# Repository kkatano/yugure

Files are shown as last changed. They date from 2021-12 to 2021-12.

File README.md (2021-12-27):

# Yugure

This project is currently primarily for experimental purposes. You are free to use the files in this project according to the license, but I do not recommend that use them as-is

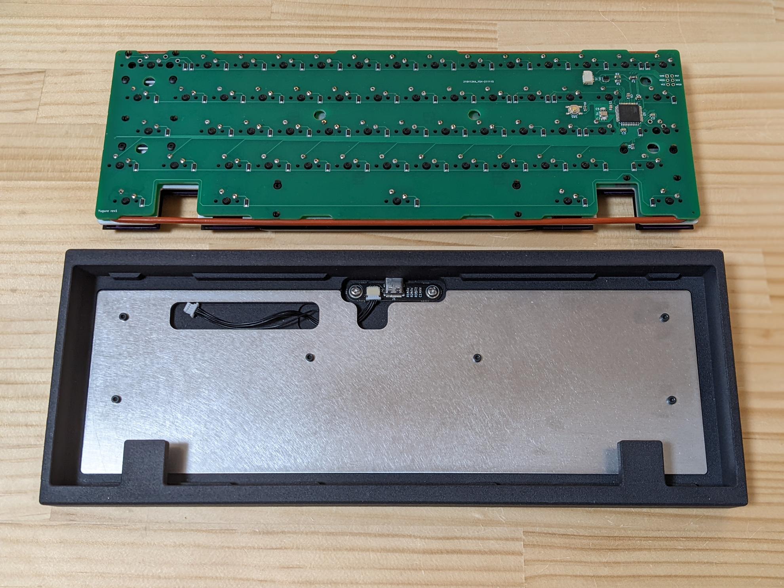
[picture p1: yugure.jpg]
Yugure


## Feature
- 60% WKL
- O-ring mount (friction fit)
- Single piece tray case
- Designed for SLS 3D printing

## Context
- I've never made a WKL board before and wanted to try it out
- Experimenting with some concepts
 - Unique gasket post location and shape. Testing how they affect the typing feel
 - Design of weight in tray case. Exploring the size and location of weight that are effective in reducing unwanted hollow sound, rather than making the case heavier

## Parts Guide
- Case
  - Use the the files contained in `case` directory
  - `case.step` is the design of the case. Order it from a service that supports SLS 3D printing
  - `weight.dxf` is the design of the weight to be attached to the case. Order 1.5mm thick from laser cutting service
  - Use 6 * 5mm M2 screws to secure the board
- PCB
  - Use the the files contained in `production` directory
  - The files is designed for ordering on JLCPCB. If you are ordering from any other manufacturer, please modify it as necessary
- Plate
  - Use the dxf files contained in `plate` directory
  - Order 1.5mm thick from laser cutting service
- Daughterboard
  - Use the [b-ken-ko's daughterboard](https://github.com/xyzz/b-ken-ko)
  - Use 2 * 3mm M3 screws to secure the board
- O-ring
  - Material: Silicone
  - Durometer(Hardness): 50A
  - AS568 number: 262
  - CS(Thickness): 3.53mm
  - ID(Inner Diameter): 177.39mm
  - OD(Outer Diameter): 184.45mm

## Notes
- This project is experimental and is not designed for serious use like production run
- You may be able to adjust the typing feel by changing the position and size of the mounting post
- There is a mounting post under the blocker, which may be difficult to make with CNC machining
- The PCB design includes the [MX_Alps_Hybrid](https://github.com/ai03-2725/MX_Alps_Hybrid/tree/b2517004a92a2ea354670c713a1530817f9da6df) designed by ai03 as a submodule. It is distributed under the MIT license

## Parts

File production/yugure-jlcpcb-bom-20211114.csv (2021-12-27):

Designator | Comment | Footprint | LCSC Part #
C1 C2 C3 | 0.1u | Capacitor_SMD:C_0805_2012Metric | C49678
C4 | 10u | Capacitor_SMD:C_0805_2012Metric | C15850
C5 C7 | 22p | Capacitor_SMD:C_0805_2012Metric | C1804
C6 | 1u | Capacitor_SMD:C_0805_2012Metric | C28323
D60 D59 D58 D57 D56 D55 D54 D53 D52 D51 D50 D49 D48 D47 D46 D45 D44 D43 D42 D41 D40 D39 D38 D37 D36 D35 D34 D33 D32 D31 D30 D29 D28 D27 D26 D25 D24 D23 D22 D21 D20 D19 D18 D17 D16 D15 D14 D13 D12 D11 D10 D9 D8 D7 D6 D5 D4 D3 D2 D1 | 1N4148 | Diode_SMD:D_SOD-123 | C81598
F1 | 500mA | Fuse:Fuse_1206_3216Metric | C70076
J1 | JST SH 4-pin | Connector_JST:JST_SH_SM04B-SRSS-TB_1x04-1MP_P1.00mm_Horizontal | C160404
R1 R2 | 22 | Resistor_SMD:R_0805_2012Metric | C17561
R4 R3 | 10k | Resistor_SMD:R_0805_2012Metric | C17414
SW1 | Reset | Button_Switch_SMD:SW_SPST_TL3342 | C318884
U1 | SRV05-4 | Package_TO_SOT_SMD:SOT-23-6 | C85364
U2 | ATmega32U4-AU | Package_QFP:TQFP-44_10x10mm_P0.8mm | C44854
Y1 | 16MHz | Crystal:Crystal_SMD_3225-4Pin_3.2x2.5mm | C13738

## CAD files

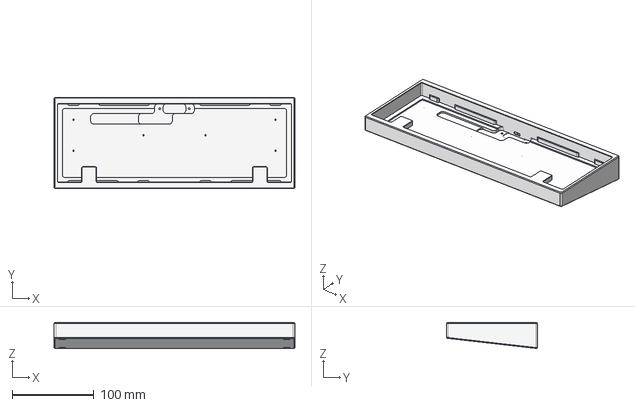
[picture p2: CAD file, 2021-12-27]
case/case.step
295.7 x 112.2 x 32.0 mm

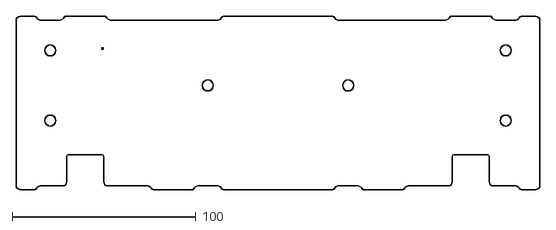
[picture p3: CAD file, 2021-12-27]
pcb/pcb-outline.dxf
284.7 x 94.2

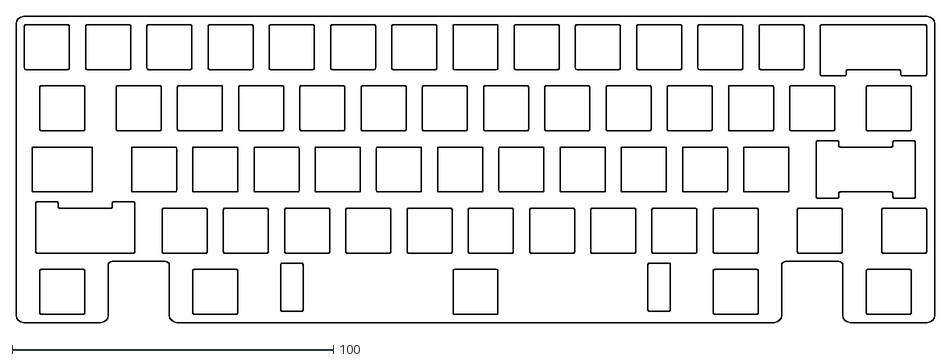
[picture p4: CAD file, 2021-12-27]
plate/plate.dxf
285.8 x 95.2

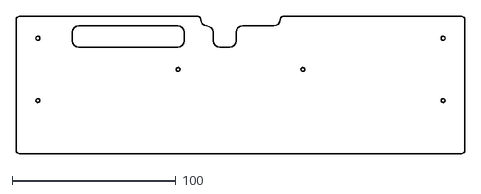
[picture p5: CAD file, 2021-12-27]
case/weight.dxf
274.3 x 83.8

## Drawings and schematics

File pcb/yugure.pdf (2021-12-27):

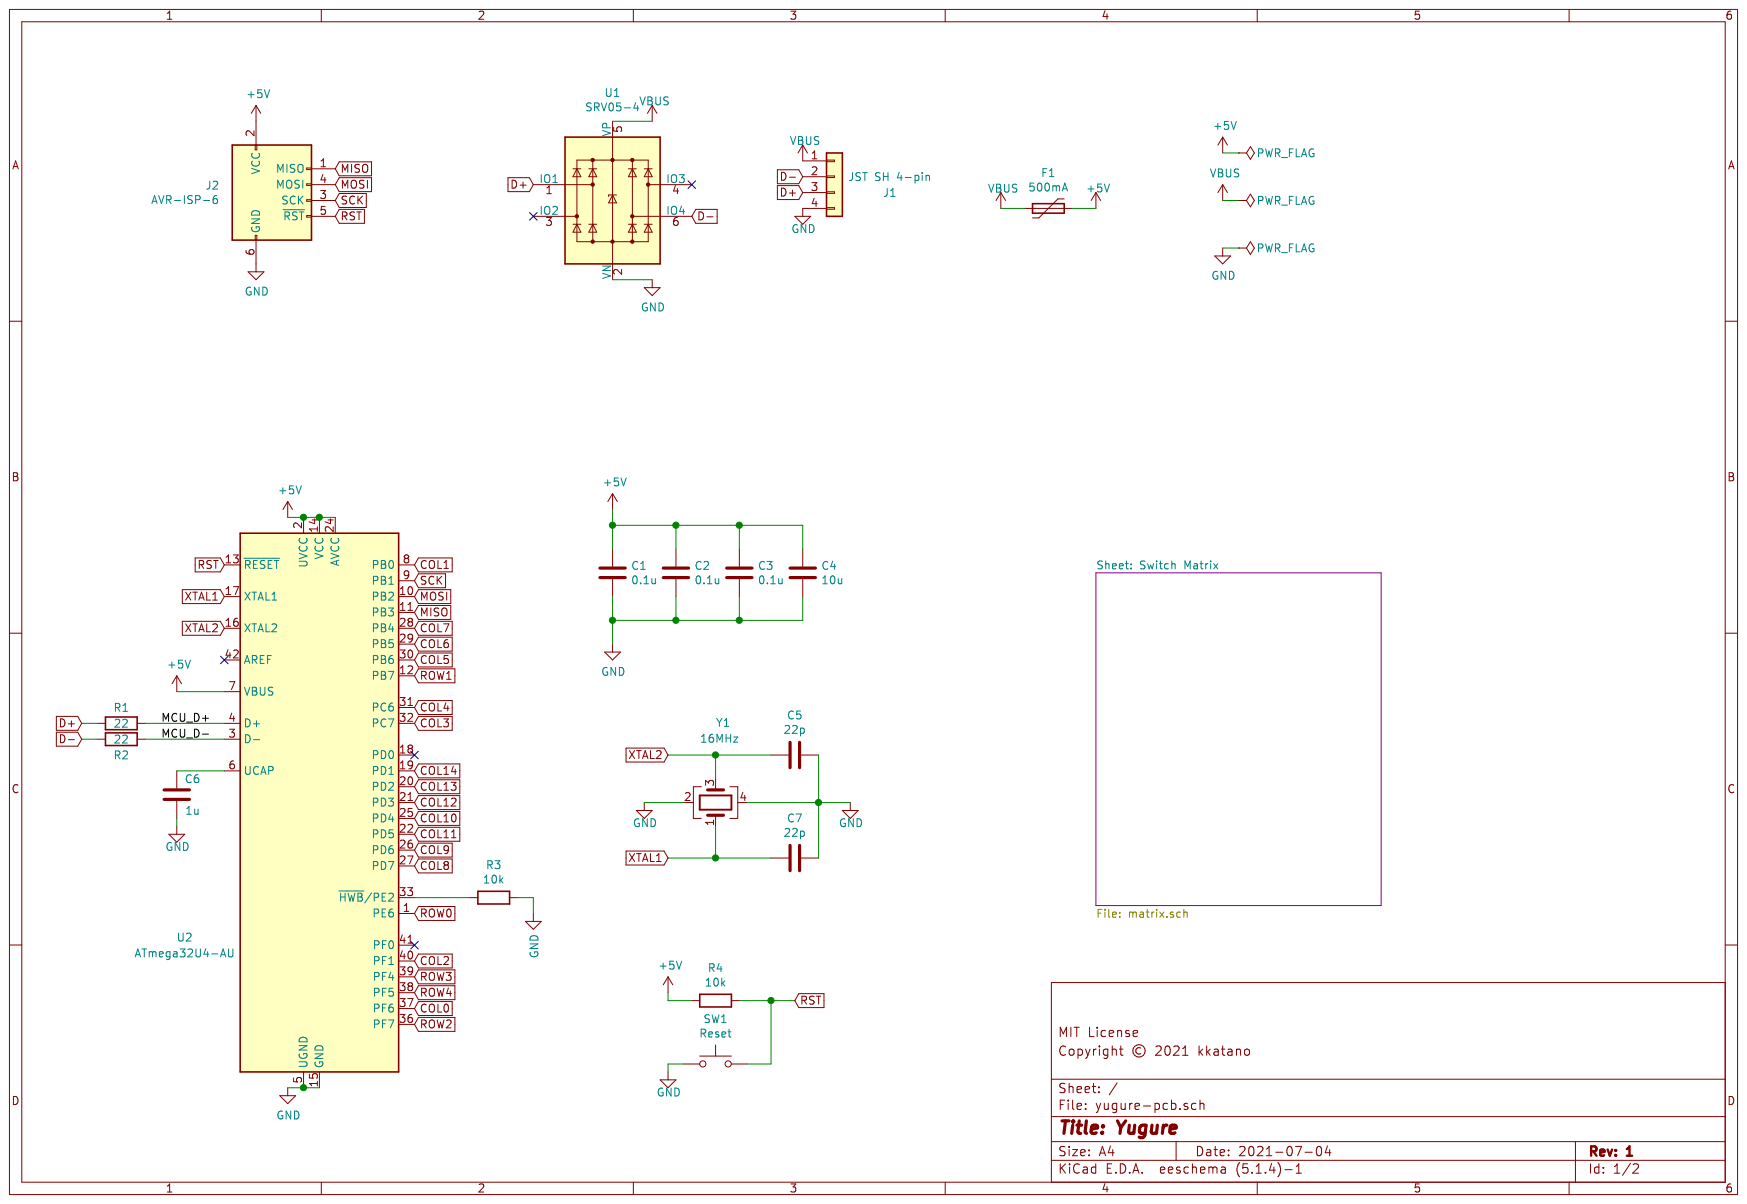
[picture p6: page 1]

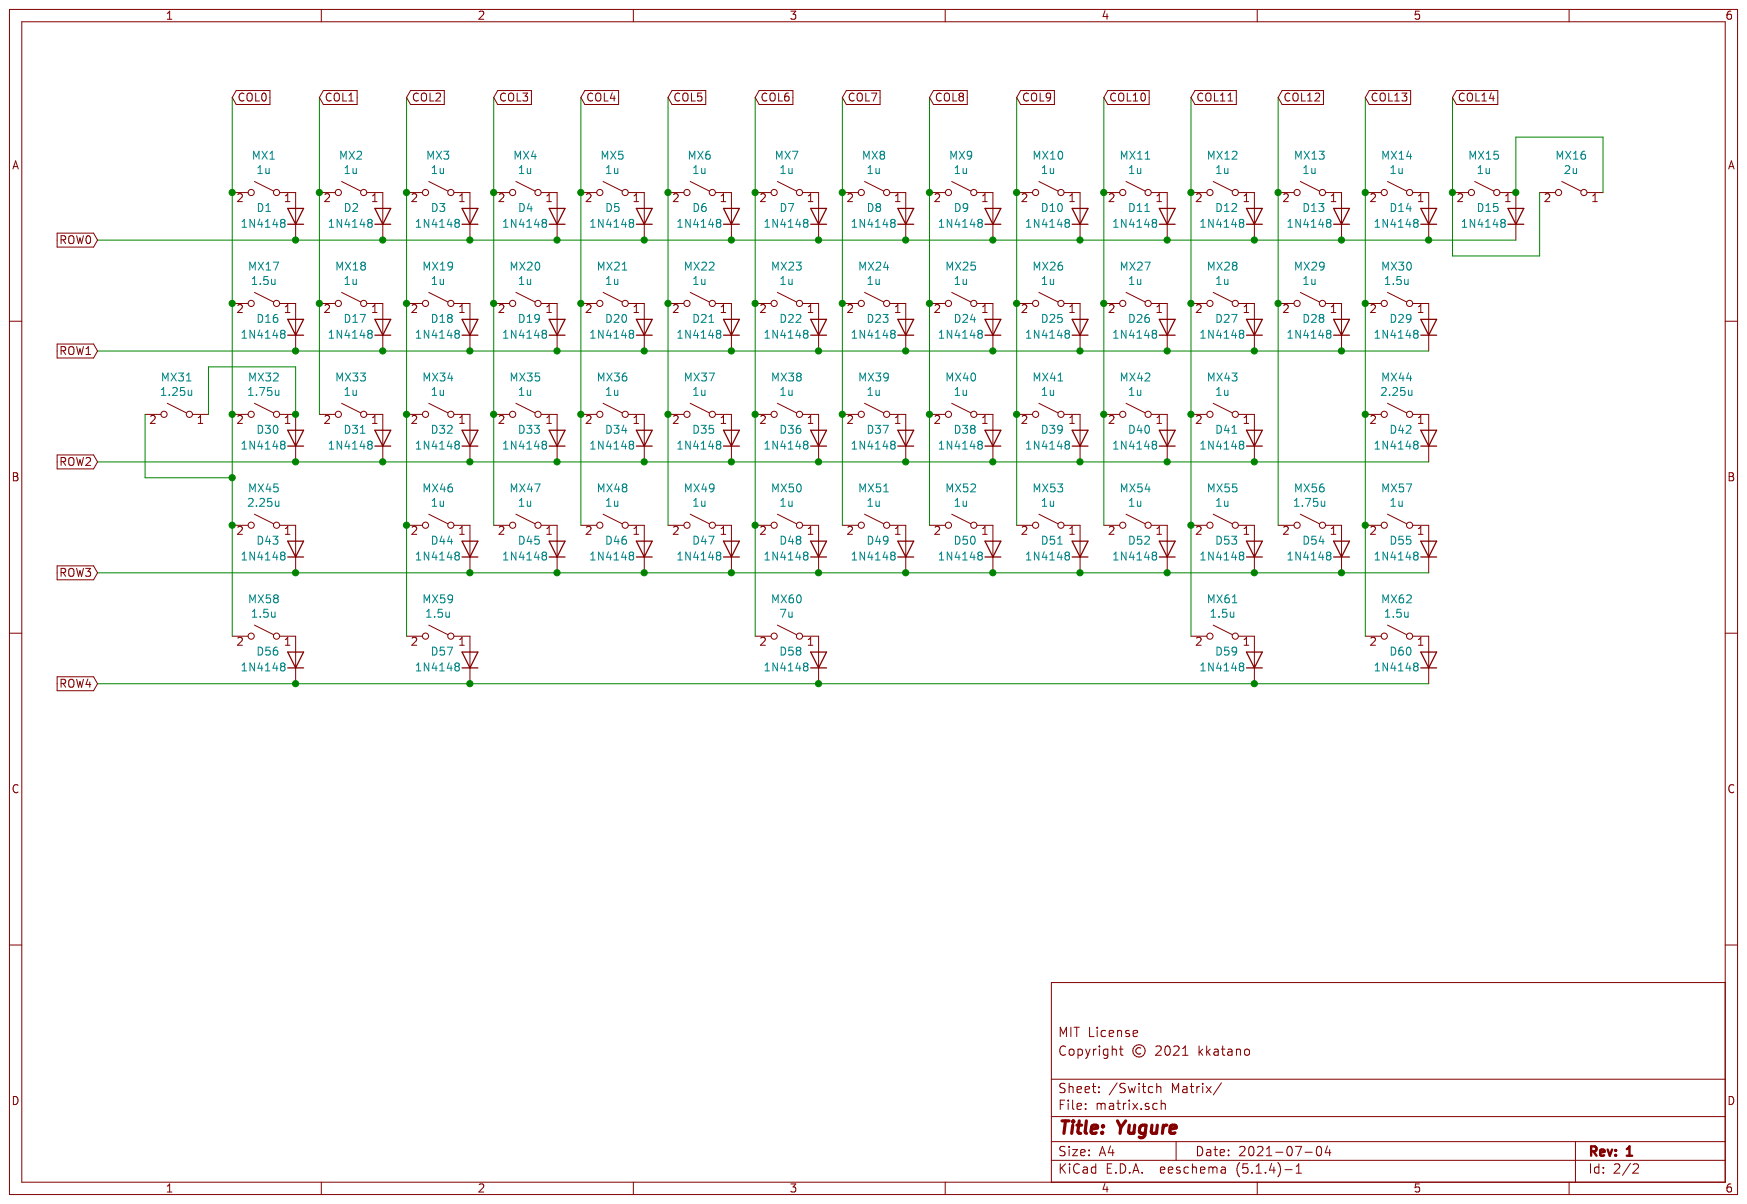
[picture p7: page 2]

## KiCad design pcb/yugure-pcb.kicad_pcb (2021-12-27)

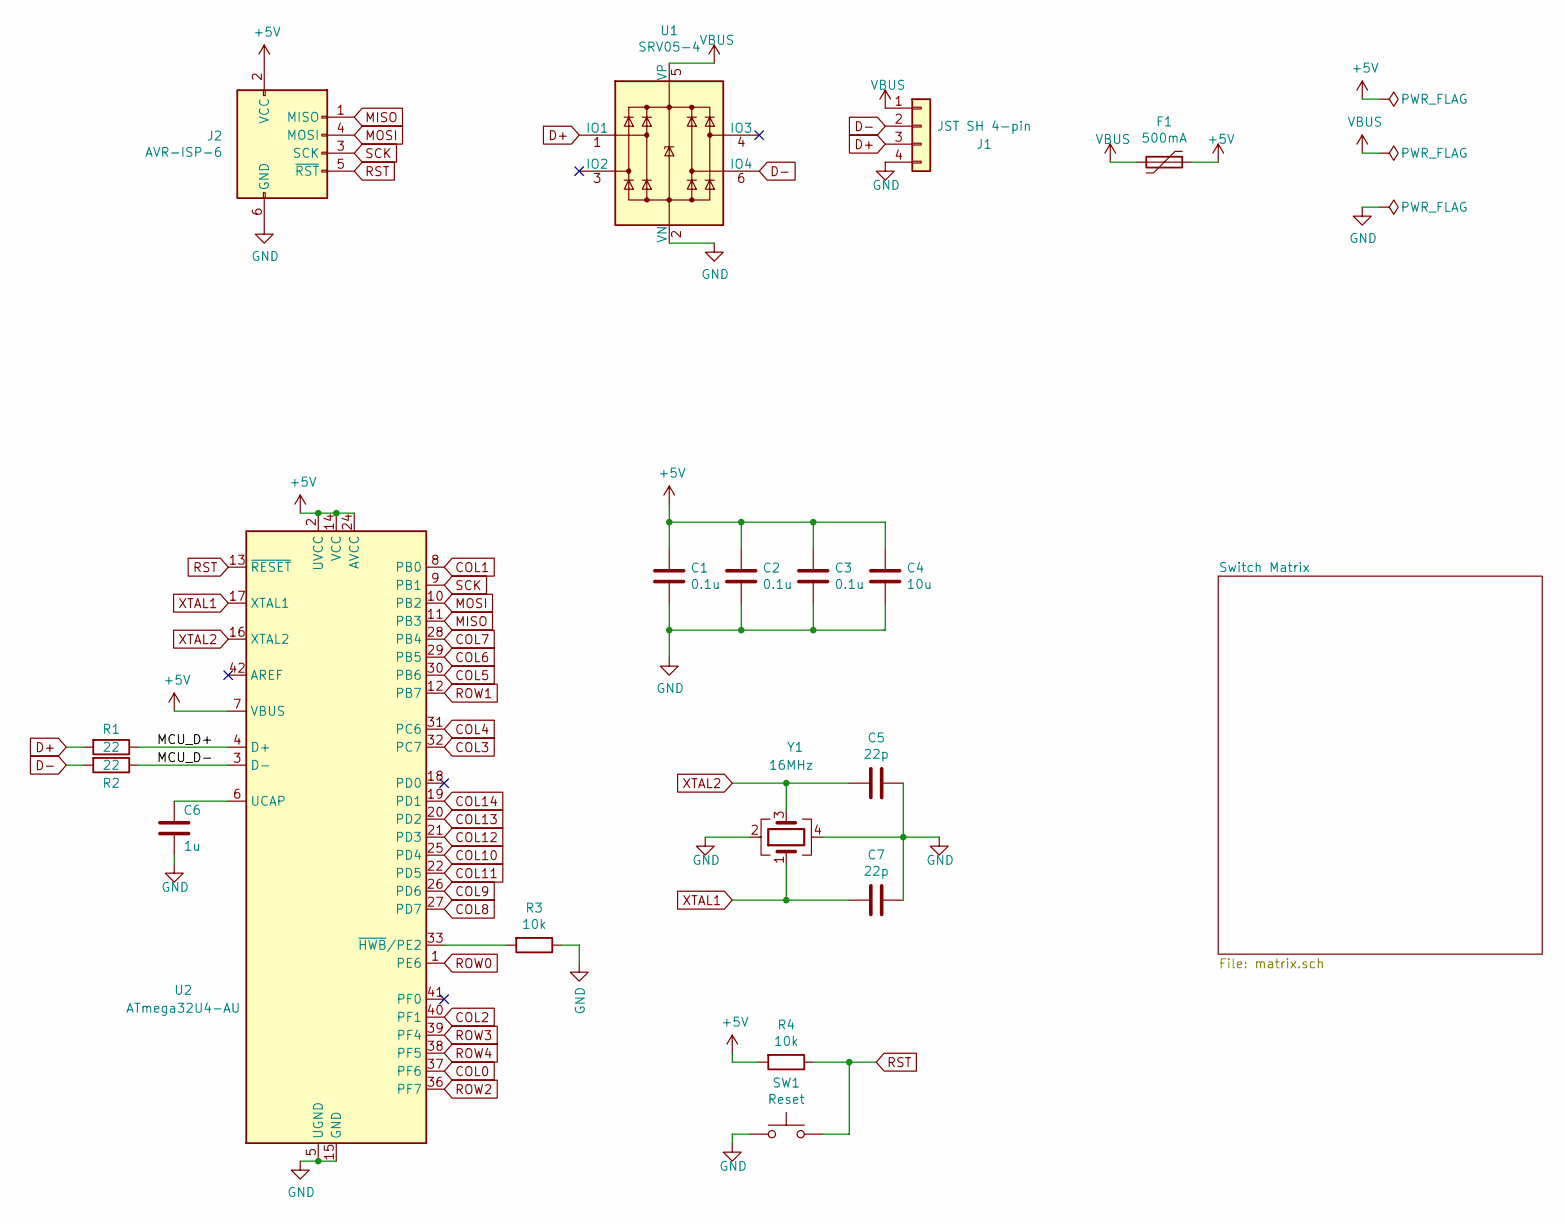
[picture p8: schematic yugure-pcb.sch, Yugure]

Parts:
C1, C2, C3: 0.1u; C_0805_2012Metric; LCSC Part # C49678
C4: 10u; C_0805_2012Metric; LCSC Part # C15850
C5, C7: 22p; C_0805_2012Metric; LCSC Part # C1804
C6: 1u; C_0805_2012Metric; LCSC Part # C28323
F1: 500mA; Fuse_1206_3216Metric; LCSC Part # C70076
J1: JST SH 4-pin; JST_SH_SM04B-SRSS-TB_1x04-1MP_P1.00mm_Horizontal; LCSC Part # C160404
J2: AVR-ISP-6; ISP
R1, R2: 22; R_0805_2012Metric; LCSC Part # C17561
R3, R4: 10k; R_0805_2012Metric; LCSC Part # C17414
SW1: Reset; SW_SPST_TL3342; LCSC Part # C318884
U1: SRV05-4; SOT-23-6; LCSC Part # C85364
U2: ATmega32U4-AU; TQFP-44_10x10mm_P0.8mm; LCSC Part # C44854
Y1: 16MHz; Crystal_SMD_3225-4Pin_3.2x2.5mm; LCSC Part # C13738

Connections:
+5V: C1.1, C2.1, C3.1, C4.1, F1.1, J2.2 (VCC), R4.2, U2.2 (UVCC), U2.7 (VBUS), U2.14 (VCC), U2.24 (AVCC), U2.34 (VCC), U2.44 (AVCC)
/MCU_D+: R1.1, U2.4 (D+)
/MCU_D-: R2.1, U2.3 (D-)
COL0: U2.37 (PF6); also elsewhere on the board
COL1: U2.8 (PB0); also elsewhere on the board
COL2: U2.40 (PF1); also elsewhere on the board
COL3: U2.32 (PC7); also elsewhere on the board
COL4: U2.31 (PC6); also elsewhere on the board
COL5: U2.30 (PB6); also elsewhere on the board
COL6: U2.29 (PB5); also elsewhere on the board
COL7: U2.28 (PB4); also elsewhere on the board
COL8: U2.27 (PD7); also elsewhere on the board
COL9: U2.26 (PD6); also elsewhere on the board
COL10: U2.25 (PD4); also elsewhere on the board
COL11: U2.22 (PD5); also elsewhere on the board
COL12: U2.21 (PD3); also elsewhere on the board
COL13: U2.20 (PD2); also elsewhere on the board
COL14: U2.19 (PD1); also elsewhere on the board
D+: J1.3, R1.2, U1.1 (IO1)
D-: J1.2, R2.2, U1.6 (IO4)
GND: C1.2, C2.2, C3.2, C4.2, C5.1, C6.2, C7.1, J1.4, J2.6 (GND), R3.1, SW1.1, U1.2 (VN), U2.5 (UGND), U2.15 (GND), U2.23 (GND), U2.35 (GND), U2.43 (GND), Y1.2, Y1.4
MISO: J2.1 (MISO), U2.11 (PB3)
MOSI: J2.4 (MOSI), U2.10 (PB2)
unnamed: C6.1, U2.6 (UCAP)
unnamed: R3.2, U2.33 (~HWB~/PE2)
ROW0: U2.1 (PE6); also elsewhere on the board
ROW1: U2.12 (PB7); also elsewhere on the board
ROW2: U2.36 (PF7); also elsewhere on the board
ROW3: U2.39 (PF4); also elsewhere on the board
ROW4: U2.38 (PF5); also elsewhere on the board
RST: J2.5 (~RST), R4.1, SW1.2, U2.13 (~RESET)
SCK: J2.3 (SCK), U2.9 (PB1)
VBUS: F1.2, J1.1, U1.5 (VP)
XTAL1: C7.2, U2.17 (XTAL1), Y1.1
XTAL2: C5.2, U2.16 (XTAL2), Y1.3

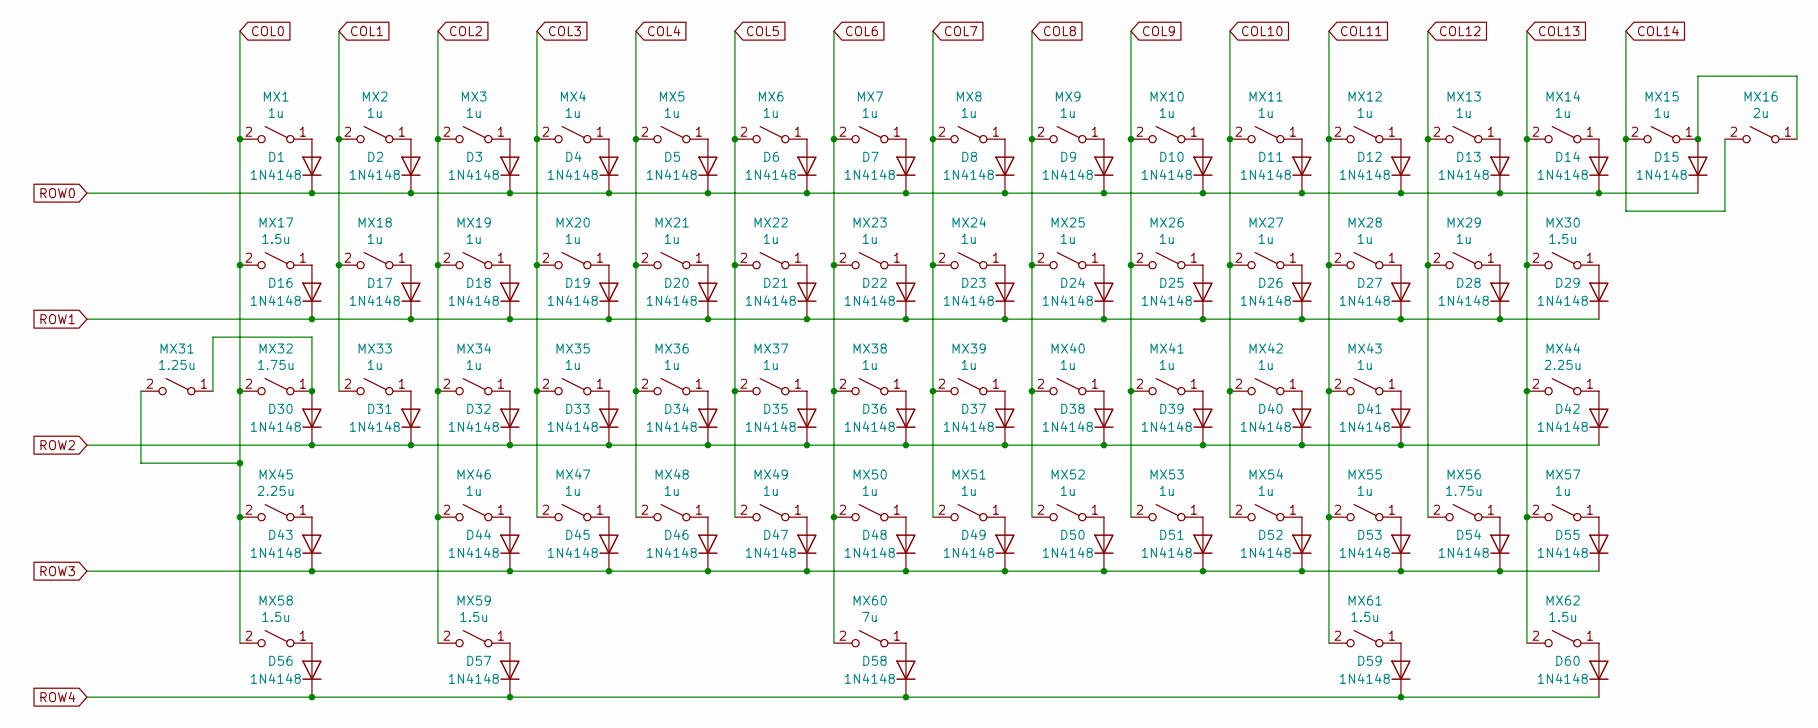
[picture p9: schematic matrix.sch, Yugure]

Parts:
D1, D2, D3, D4, D5, D6, D7, D8, D9, D10, D11, D12, D13, D14, D15, D16, D17, D18, D19, D20, D21, D22, D23, D24, D25, D26, D27, D28, D29, D30, D31, D32, D33, D34, D35, D36, D37, D38, D39, D40, D41, D42, D43, D44, D45, D46, D47, D48, D49, D50, D51, D52, D53, D54, D55, D56, D57, D58, D59, D60: 1N4148; D_SOD-123; LCSC Part # C81598
MX1, MX2, MX3, MX4, MX5, MX6, MX7, MX8, MX9, MX10, MX11, MX12, MX13, MX14, MX15, MX18, MX19, MX20, MX21, MX22, MX23, MX24, MX25, MX26, MX27, MX28, MX29, MX33, MX34, MX35, MX36, MX37, MX38, MX39, MX40, MX41, MX42, MX43, MX46, MX47, MX48, MX49, MX50, MX51, MX52, MX53, MX54, MX55, MX57: 1u; MXOnly-1U-NoLED
MX16: 2u; MXOnly-2U-NoLED
MX17, MX30, MX58, MX59, MX61, MX62: 1.5u; MXOnly-1.5U-NoLED
MX31: 1.25u; MXOnly-1.25U-NoLED
MX32, MX56: 1.75u; MXOnly-1.75U-NoLED
MX44: 2.25u; MXOnly-2.25U-NoLED
MX45: 2.25u; MXOnly-2.25U-ReversedStabilizers-NoLED
MX60: 7u; MXOnly-7U-ReversedStabilizers-NoLED

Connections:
COL0: MX1.2 (B), MX17.2 (B), MX31.2 (B), MX32.2 (B), MX45.2 (B), MX58.2 (B); also elsewhere on the board
COL1: MX2.2 (B), MX18.2 (B), MX33.2 (B); also elsewhere on the board
COL2: MX3.2 (B), MX19.2 (B), MX34.2 (B), MX46.2 (B), MX59.2 (B); also elsewhere on the board
COL3: MX4.2 (B), MX20.2 (B), MX35.2 (B), MX47.2 (B); also elsewhere on the board
COL4: MX5.2 (B), MX21.2 (B), MX36.2 (B), MX48.2 (B); also elsewhere on the board
COL5: MX6.2 (B), MX22.2 (B), MX37.2 (B), MX49.2 (B); also elsewhere on the board
COL6: MX7.2 (B), MX23.2 (B), MX38.2 (B), MX50.2 (B), MX60.2 (B); also elsewhere on the board
COL7: MX8.2 (B), MX24.2 (B), MX39.2 (B), MX51.2 (B); also elsewhere on the board
COL8: MX9.2 (B), MX25.2 (B), MX40.2 (B), MX52.2 (B); also elsewhere on the board
COL9: MX10.2 (B), MX26.2 (B), MX41.2 (B), MX53.2 (B); also elsewhere on the board
COL10: MX11.2 (B), MX27.2 (B), MX42.2 (B), MX54.2 (B); also elsewhere on the board
COL11: MX12.2 (B), MX28.2 (B), MX43.2 (B), MX55.2 (B), MX61.2 (B); also elsewhere on the board
COL12: MX13.2 (B), MX29.2 (B), MX56.2 (B); also elsewhere on the board
COL13: MX14.2 (B), MX30.2 (B), MX44.2 (B), MX57.2 (B), MX62.2 (B); also elsewhere on the board
COL14: MX15.2 (B), MX16.2 (B); also elsewhere on the board
unnamed: D1.2 (A), MX1.1 (A)
unnamed: D2.2 (A), MX2.1 (A)
unnamed: D3.2 (A), MX3.1 (A)
unnamed: D4.2 (A), MX4.1 (A)
unnamed: D5.2 (A), MX5.1 (A)
unnamed: D6.2 (A), MX6.1 (A)
unnamed: D7.2 (A), MX7.1 (A)
unnamed: D8.2 (A), MX8.1 (A)
unnamed: D9.2 (A), MX9.1 (A)
unnamed: D10.2 (A), MX10.1 (A)
unnamed: D11.2 (A), MX11.1 (A)
unnamed: D12.2 (A), MX12.1 (A)
unnamed: D13.2 (A), MX13.1 (A)
unnamed: D14.2 (A), MX14.1 (A)
unnamed: D15.2 (A), MX15.1 (A), MX16.1 (A)
unnamed: D16.2 (A), MX17.1 (A)
unnamed: D17.2 (A), MX18.1 (A)
unnamed: D18.2 (A), MX19.1 (A)
unnamed: D19.2 (A), MX20.1 (A)
unnamed: D20.2 (A), MX21.1 (A)
unnamed: D21.2 (A), MX22.1 (A)
unnamed: D22.2 (A), MX23.1 (A)
unnamed: D23.2 (A), MX24.1 (A)
unnamed: D24.2 (A), MX25.1 (A)
unnamed: D25.2 (A), MX26.1 (A)
unnamed: D26.2 (A), MX27.1 (A)
unnamed: D27.2 (A), MX28.1 (A)
unnamed: D28.2 (A), MX29.1 (A)
unnamed: D29.2 (A), MX30.1 (A)
unnamed: D30.2 (A), MX31.1 (A), MX32.1 (A)
unnamed: D31.2 (A), MX33.1 (A)
unnamed: D32.2 (A), MX34.1 (A)
unnamed: D33.2 (A), MX35.1 (A)
unnamed: D34.2 (A), MX36.1 (A)
unnamed: D35.2 (A), MX37.1 (A)
unnamed: D36.2 (A), MX38.1 (A)
unnamed: D37.2 (A), MX39.1 (A)
unnamed: D38.2 (A), MX40.1 (A)
unnamed: D39.2 (A), MX41.1 (A)
unnamed: D40.2 (A), MX42.1 (A)
unnamed: D41.2 (A), MX43.1 (A)
unnamed: D42.2 (A), MX44.1 (A)
unnamed: D43.2 (A), MX45.1 (A)
unnamed: D44.2 (A), MX46.1 (A)
unnamed: D45.2 (A), MX47.1 (A)
unnamed: D46.2 (A), MX48.1 (A)
unnamed: D47.2 (A), MX49.1 (A)
unnamed: D48.2 (A), MX50.1 (A)
unnamed: D49.2 (A), MX51.1 (A)
unnamed: D50.2 (A), MX52.1 (A)
unnamed: D51.2 (A), MX53.1 (A)
unnamed: D52.2 (A), MX54.1 (A)
unnamed: D53.2 (A), MX55.1 (A)
unnamed: D54.2 (A), MX56.1 (A)
unnamed: D55.2 (A), MX57.1 (A)
unnamed: D56.2 (A), MX58.1 (A)
unnamed: D57.2 (A), MX59.1 (A)
unnamed: D58.2 (A), MX60.1 (A)
unnamed: D59.2 (A), MX61.1 (A)
unnamed: D60.2 (A), MX62.1 (A)
ROW0: D1.1 (K), D2.1 (K), D3.1 (K), D4.1 (K), D5.1 (K), D6.1 (K), D7.1 (K), D8.1 (K), D9.1 (K), D10.1 (K), D11.1 (K), D12.1 (K), D13.1 (K), D14.1 (K), D15.1 (K); also elsewhere on the board
ROW1: D16.1 (K), D17.1 (K), D18.1 (K), D19.1 (K), D20.1 (K), D21.1 (K), D22.1 (K), D23.1 (K), D24.1 (K), D25.1 (K), D26.1 (K), D27.1 (K), D28.1 (K), D29.1 (K); also elsewhere on the board
ROW2: D30.1 (K), D31.1 (K), D32.1 (K), D33.1 (K), D34.1 (K), D35.1 (K), D36.1 (K), D37.1 (K), D38.1 (K), D39.1 (K), D40.1 (K), D41.1 (K), D42.1 (K); also elsewhere on the board
ROW3: D43.1 (K), D44.1 (K), D45.1 (K), D46.1 (K), D47.1 (K), D48.1 (K), D49.1 (K), D50.1 (K), D51.1 (K), D52.1 (K), D53.1 (K), D54.1 (K), D55.1 (K); also elsewhere on the board
ROW4: D56.1 (K), D57.1 (K), D58.1 (K), D59.1 (K), D60.1 (K); also elsewhere on the board

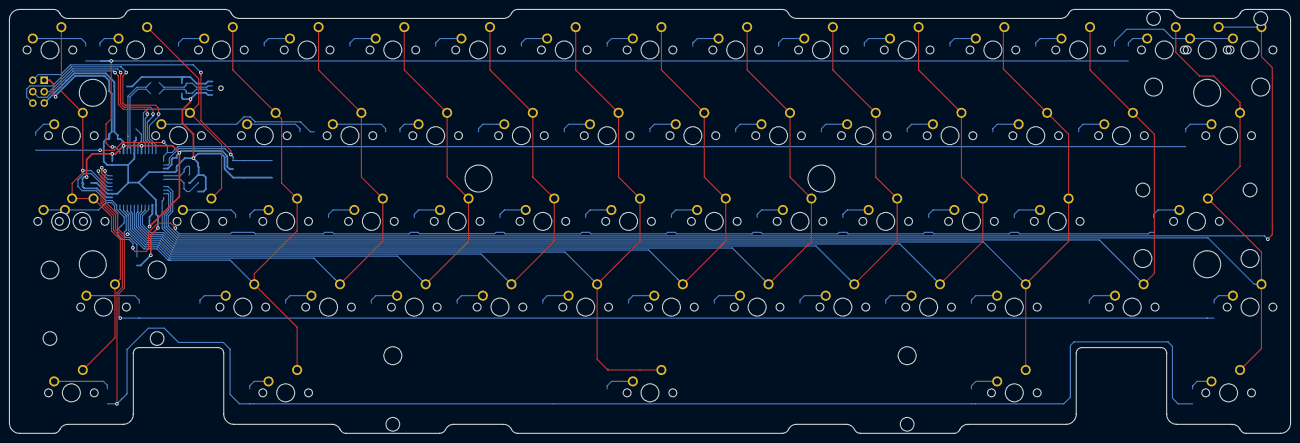
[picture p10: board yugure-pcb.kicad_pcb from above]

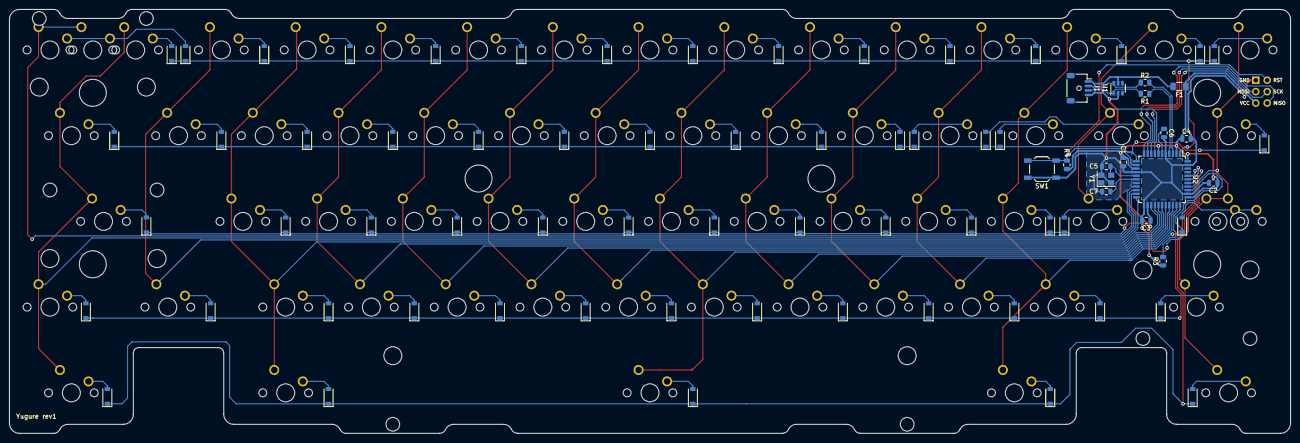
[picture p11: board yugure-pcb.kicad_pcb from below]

Board: 2 copper layers, 284.7 x 94.2 mm, 140 parts (78 on the bottom side), 95 nets.

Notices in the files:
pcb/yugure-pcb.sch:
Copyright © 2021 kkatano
